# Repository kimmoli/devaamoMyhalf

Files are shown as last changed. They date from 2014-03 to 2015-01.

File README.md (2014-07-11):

devaamoMyhalf
=============

Myhalf edition for Devaamo

V1.10 Original design based on kimmoli Myhalf

V1.20 SMD connector added, pogopads relocated and resized to 2 mm dia, flash hole relocated

*V1.20 Shared at OSHPark https://oshpark.com/shared_projects/6TWMNB35*

Added stl files for clips, 0.8mm and 1.6mm PCB thicknesses.

See also http://talk.maemo.org/showthread.php?t=92329

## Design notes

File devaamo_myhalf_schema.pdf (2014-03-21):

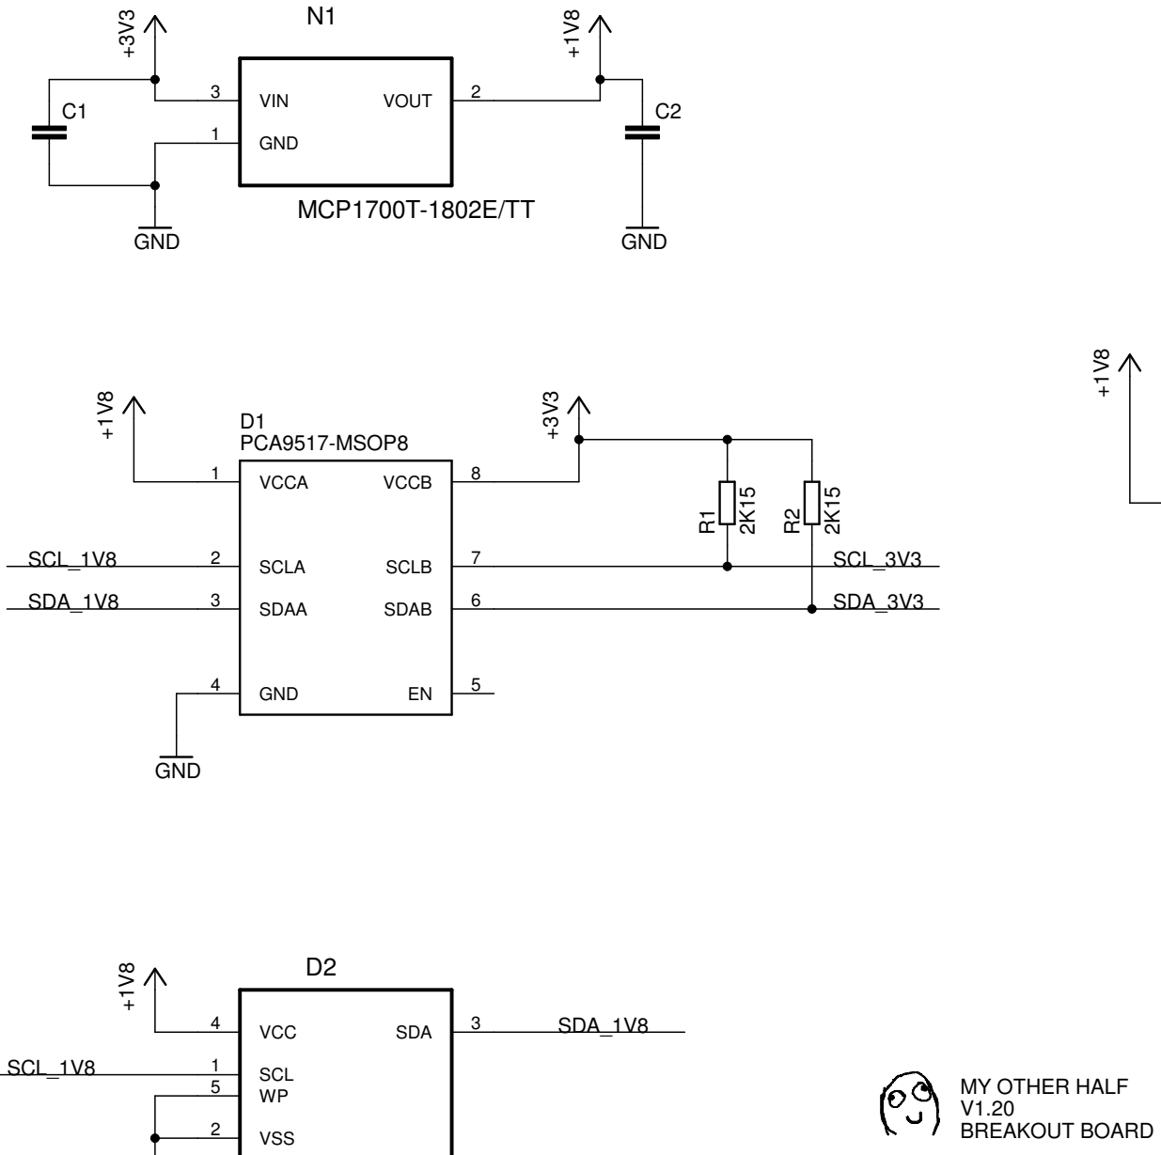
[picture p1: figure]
PCA9517-MSOP8; MCP1700T-1802E/TT; GND; MY OTHER HALF V1.20 BREAKOUT BOARD; VCC 4; SCL 1 WP 5; VSS 2; SDA; VCCA 1; SCLA 2; SDAA 3; GND 4; SDAB; SCLB; VCCB; VIN 3; GND 1; VOUT; SDA_1V8; SCL_1V8; SCL_3V3; SDA_3V3

21.3.2014 11:49:48 f=1.25 c:\temp\TheOtherHalf\devaamoMyhalf\devaamo_myhalf.sch (Sheet: 1/1)

SMD_1.5MM

SMD_1.5MM

SMD_1.5MM

SMD_1.5MM

SMD_1.5MM

SMD_1.5MM

AT24C02C-SOT23-5

GND

GND

+3V3

330

+3V3

GND

PIIKKIRIMA-10TH

GND

+3V3

PIIKKIRIMA-10SMD-WIRE

GND

+1V8

+3V3

CONNECTION TO JOLLA

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
INT | INT

SDA_1V8

SDA_1V8 | SDA_1V8

SCL_1V8

SCL_1V8 | SCL_1V8

VCC

VCC | VCC

GND

+3V3

SCL_3V3 | SCL_3V3
SDA_3V3 | SDA_3V3

OSHW
LOGO

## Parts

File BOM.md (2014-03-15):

DevaamoMyHalf V1.20 BOM
=======================

Bill of materials

Locator | Part
--------|--------------------------------------------------------------------------------
R1, R2  | 0603 2k15 (or 2k2) I2C 3.3V pullups. I usually use 2k15 from E96 series.
R3      | 0603 330 ohms or something like that for led series resistor
C1, C2  | 0603 1µF 16V X7R
H1      | 0603 Led of your favorite colour (for blue or white, change R3)
N1      | MCP1700-1802E (Microchip) in SOT23 1.8V Regulator
        | http://ww1.microchip.com/downloads/en/DeviceDoc/20001826C.pdf
D1      | PCA9517DGKR (TI) in MSOP8 (or PCA9517DP (NXP) in TSSOP-8) I2C Level translator
        | http://www.nxp.com/documents/data_sheet/PCA9517.pdf
D3      | AT24C02D-STUM-T (Atmel) in SOT23-5 I2C EEPROM 2kbit
        | http://www.atmel.com/Images/Atmel-8871-SEEPROM-AT24C01D-02D-Datasheet.pdf
X1      | 2.54mm (0.1") pinheader 10 pins, or just solder wires (Remember to cut even on phone side)
        | SMD Headers Vertical or right-angle should also fit

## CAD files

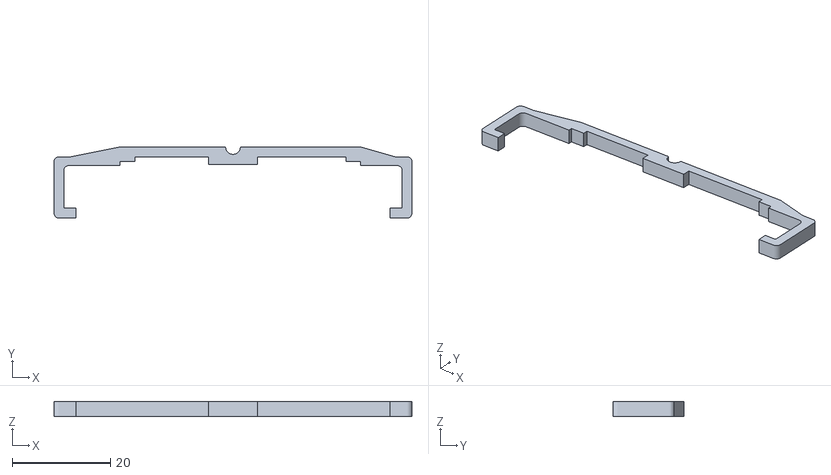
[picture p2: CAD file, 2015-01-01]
stl/Myhalf-clip-0_8mm-r2.stl
73.0 x 14.5 x 3.00

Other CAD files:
stl/Myhalf-clip-0_8mm.stl
stl/Myhalf-clip-1_6mm.stl

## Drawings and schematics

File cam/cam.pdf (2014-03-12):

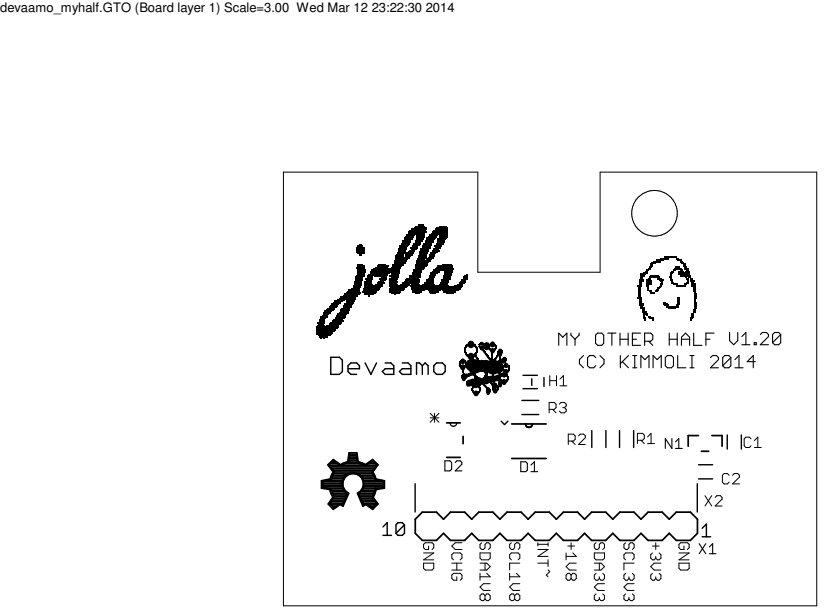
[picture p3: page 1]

devaamo_myhalf.GTO (Board layer 1) Scale=3.00 Wed Mar 12 23:22:30 2014

devaamo_myhalf.GTP (Board layer 2) Scale=3.00 Wed Mar 12 23:22:30 2014

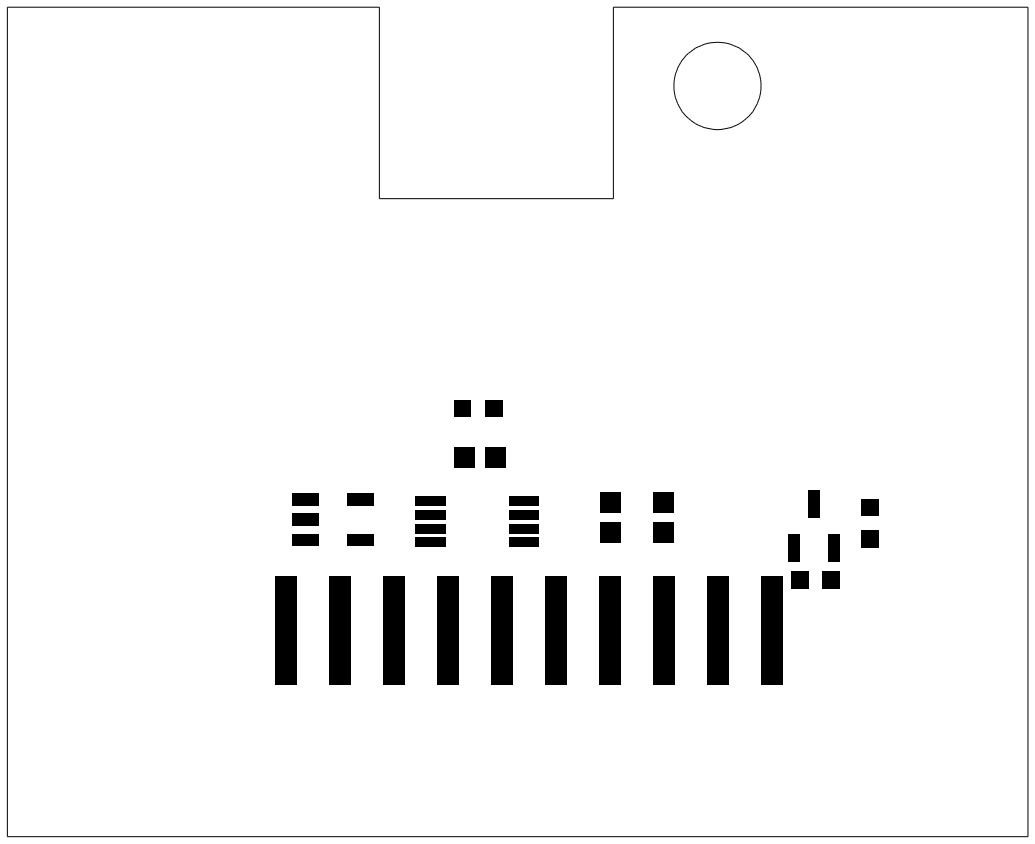
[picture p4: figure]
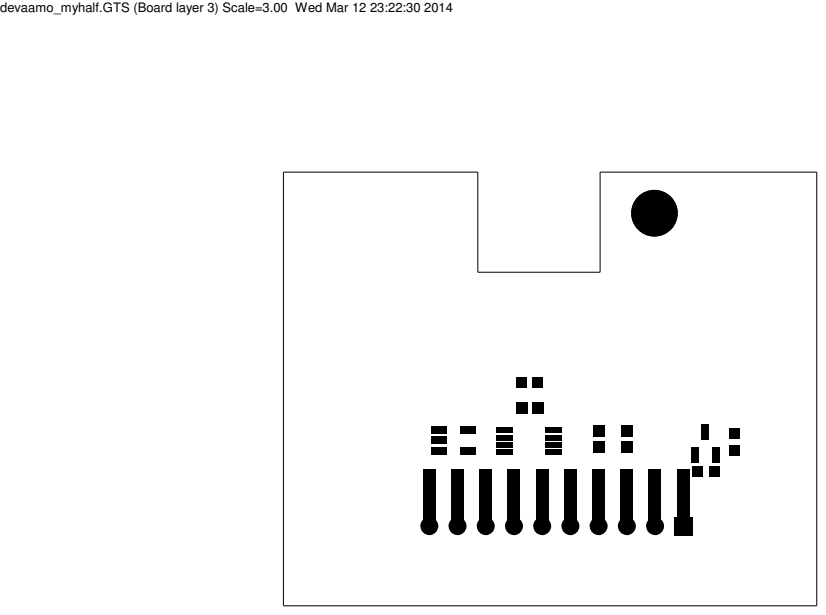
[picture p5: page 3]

devaamo_myhalf.GTS (Board layer 3) Scale=3.00 Wed Mar 12 23:22:30 2014

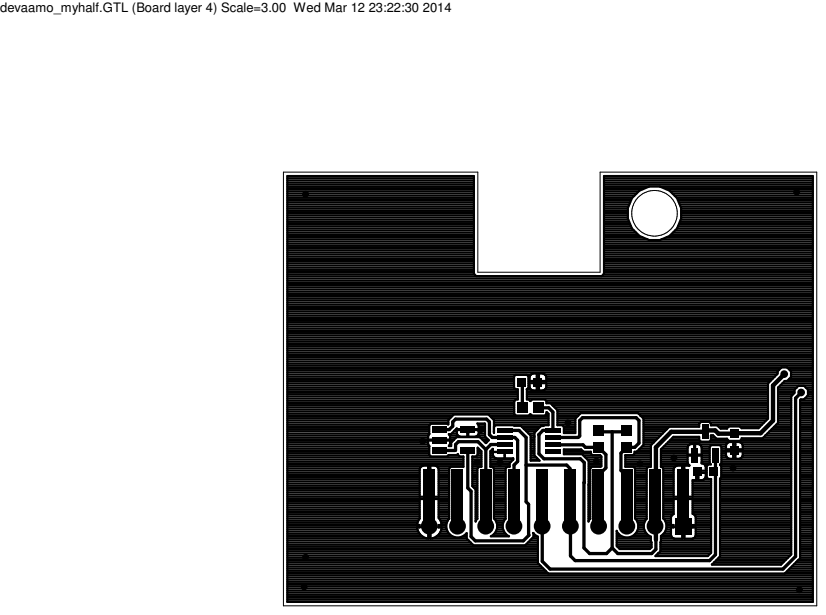
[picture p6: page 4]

devaamo_myhalf.GTL (Board layer 4) Scale=3.00 Wed Mar 12 23:22:30 2014

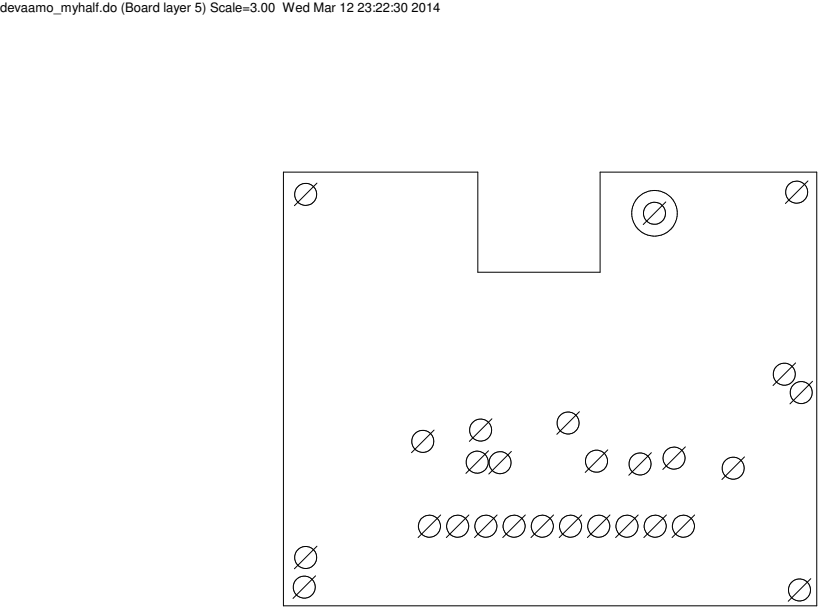
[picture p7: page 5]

devaamo_myhalf.do (Board layer 5) Scale=3.00 Wed Mar 12 23:22:30 2014

devaamo_myhalf.GML (Board layer 6) Scale=3.00 Wed Mar 12 23:22:30 2014

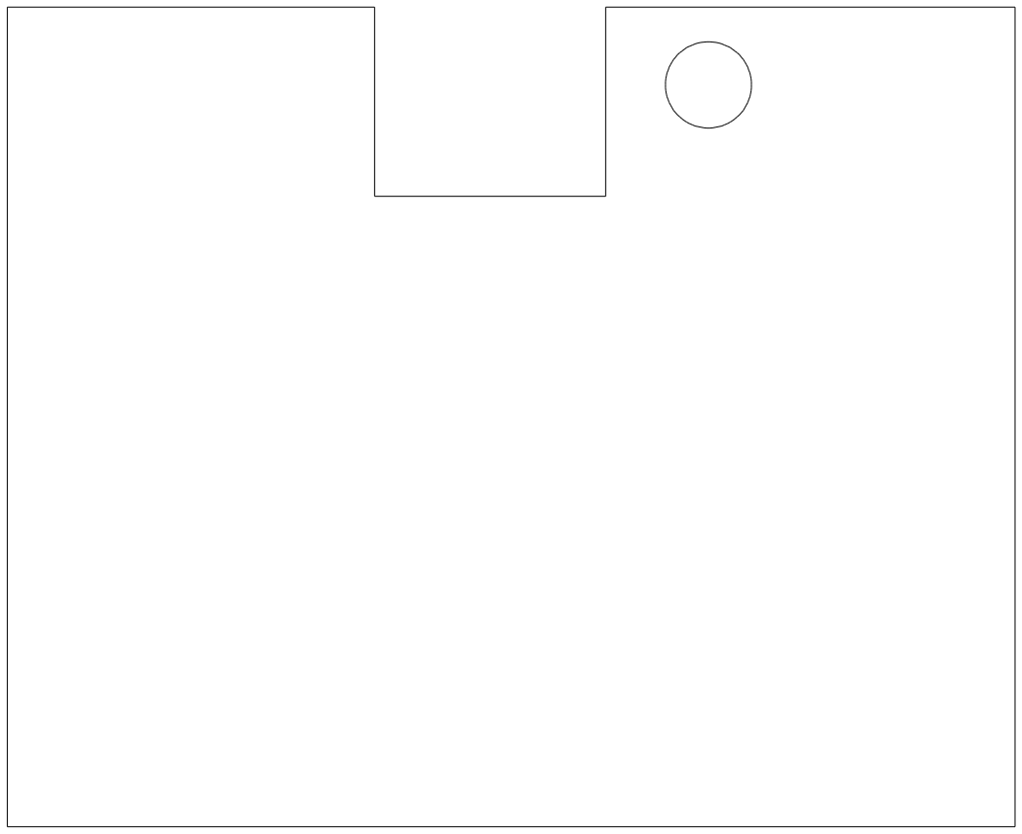
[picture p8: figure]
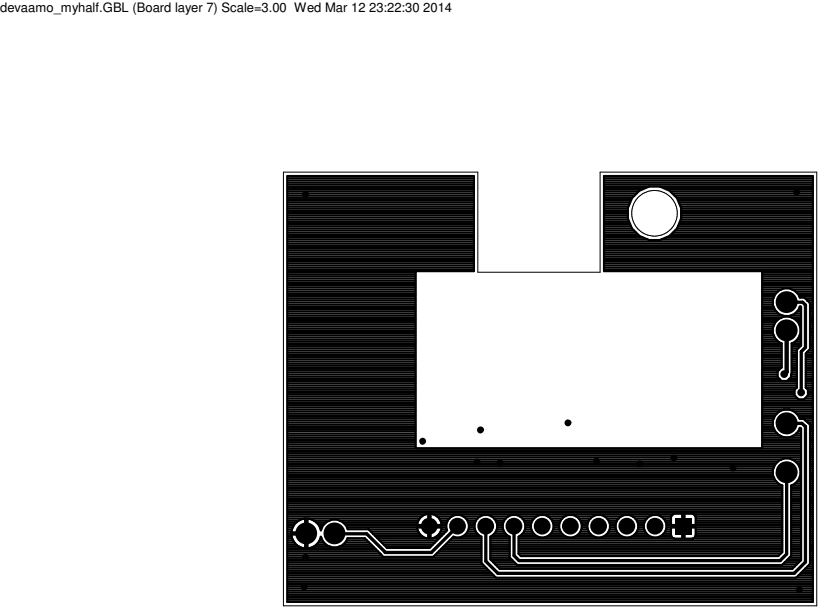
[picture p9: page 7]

devaamo_myhalf.GBL (Board layer 7) Scale=3.00 Wed Mar 12 23:22:30 2014

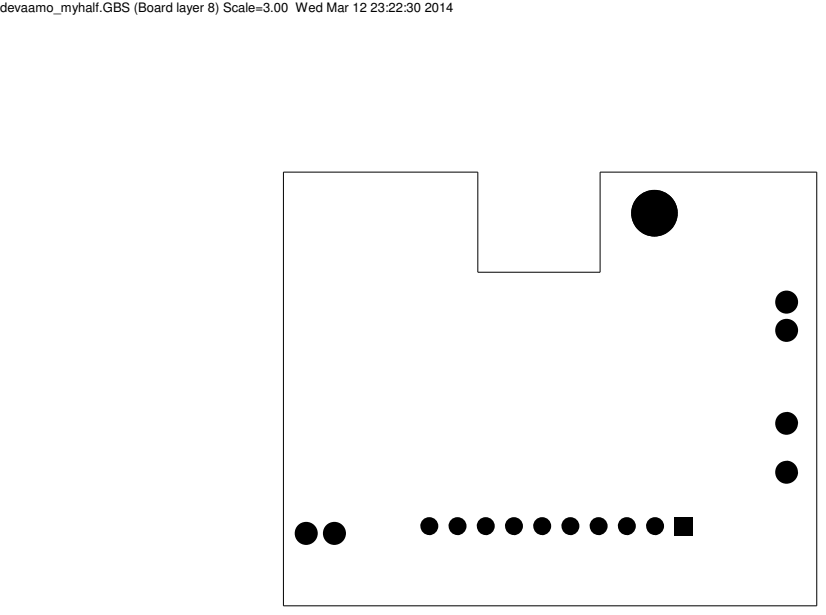
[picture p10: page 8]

devaamo_myhalf.GBS (Board layer 8) Scale=3.00 Wed Mar 12 23:22:30 2014

devaamo_myhalf.GBP (Board layer 9) Scale=3.00 Wed Mar 12 23:22:30 2014

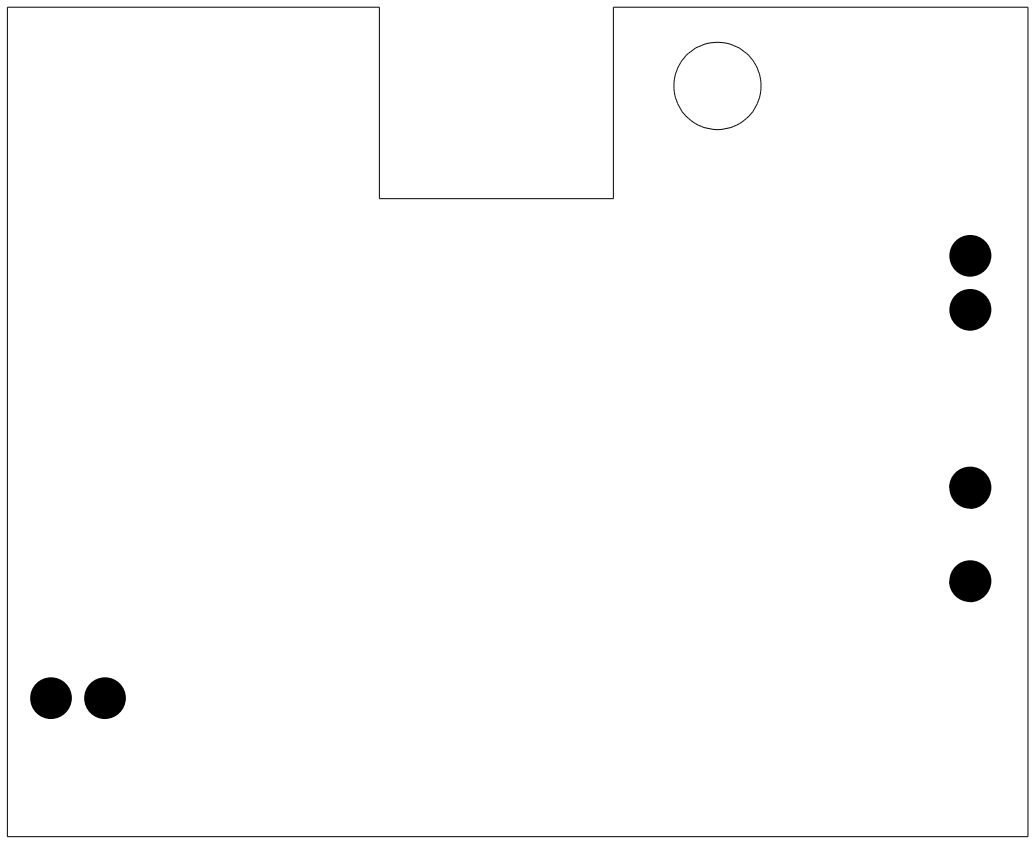
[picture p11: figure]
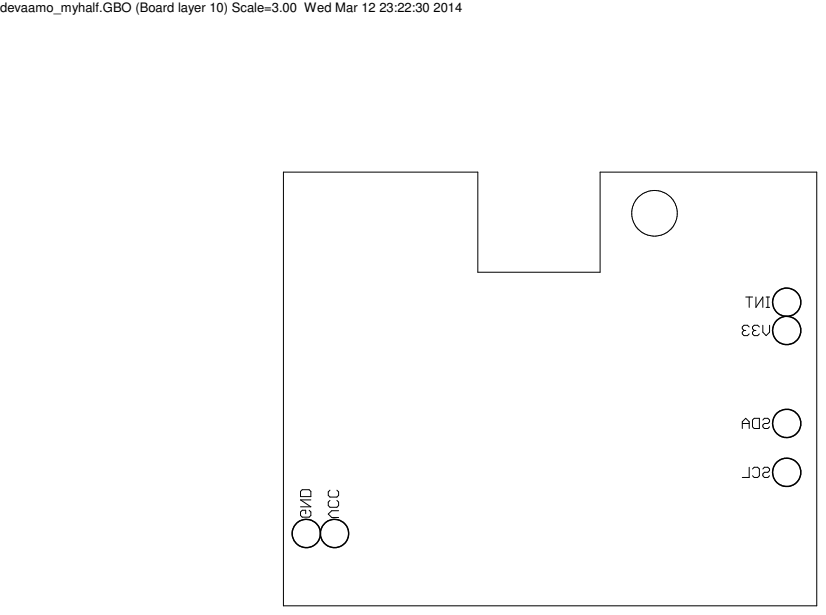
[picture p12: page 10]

devaamo_myhalf.GBO (Board layer 10) Scale=3.00 Wed Mar 12 23:22:30 2014

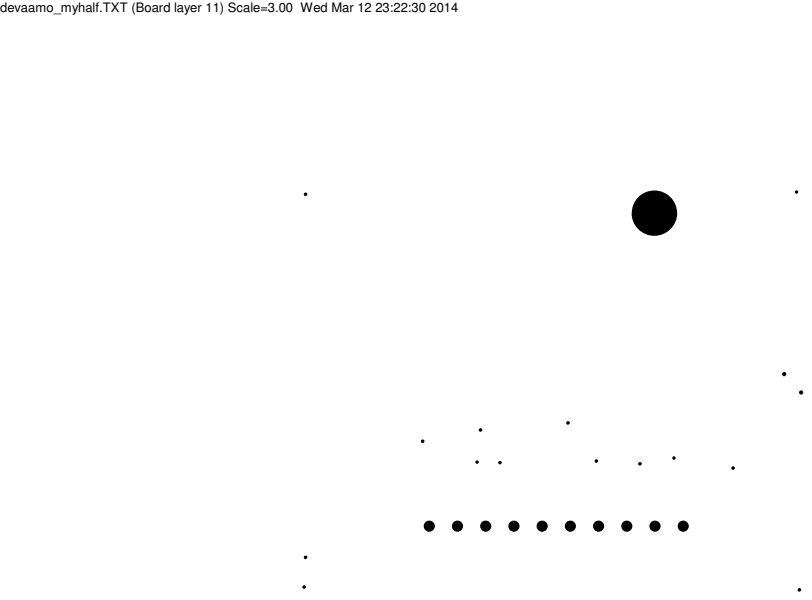
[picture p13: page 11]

devaamo_myhalf.TXT (Board layer 11) Scale=3.00 Wed Mar 12 23:22:30 2014

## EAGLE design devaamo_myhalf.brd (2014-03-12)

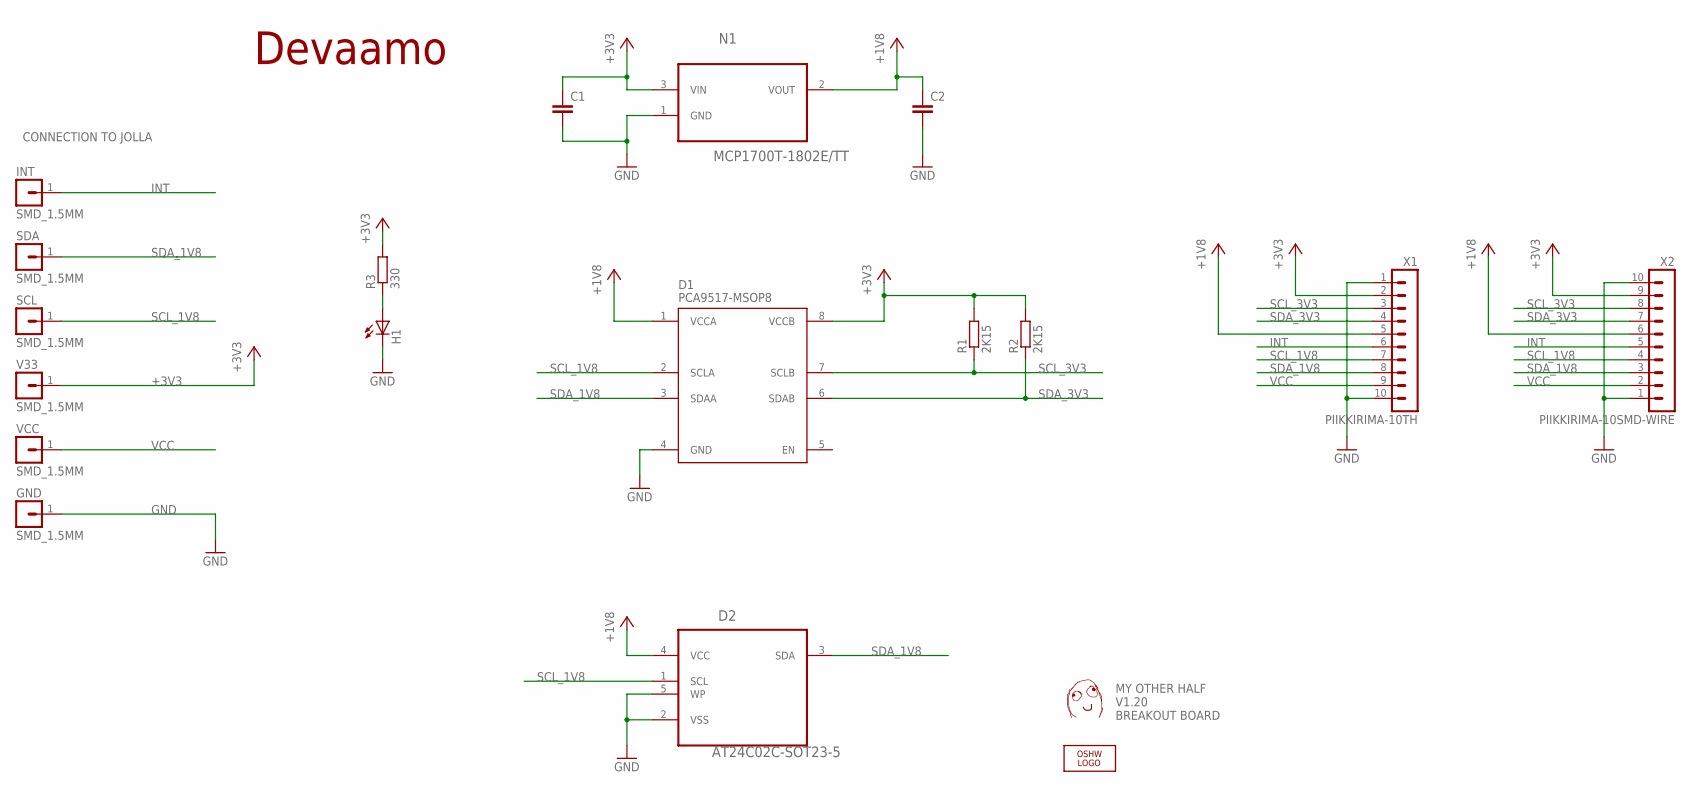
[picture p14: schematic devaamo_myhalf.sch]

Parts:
C1, C2: C-EUC0603; C0603
D1: PCA9517-MSOP8; SOP65P490X110-8N
D2: AT24C02C-SOT23-5; SOT95P280X145-5N
GND: SMD_1.5MM; SMD_ROUND_1.5MM
H1: LEDCHIP-LED0603; CHIP-LED0603
INT: SMD_1.5MM; SMD_ROUND_1.5MM
LOGO1: OSHW_LOGO_FILLX0200-NT; OSHW_FILLX200_NOTEXT
N1: MCP1700T-1802E/TT; SOT95P237X112-3N
R1, R2: 2K15; R0603
R3: 330; R0603
SCL: SMD_1.5MM; SMD_ROUND_1.5MM
SDA: SMD_1.5MM; SMD_ROUND_1.5MM
U$1: DAFUG
U$3: DEVAAMO
V33: SMD_1.5MM; SMD_ROUND_1.5MM
VCC: SMD_1.5MM; SMD_ROUND_1.5MM
X1: PIIKKIRIMA-10TH; PIIKKIRIMA-10
X2: PIIKKIRIMA-10SMD-WIRE; 61001018321

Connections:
+1V8: C2.1, D1.1 (VCCA), D2.4 (VCC), N1.2 (VOUT), X1.5, X2.6 (5)
+3V3: C1.1, D1.8 (VCCB), N1.3 (VIN), R1.2, R2.2, R3.2, V33.1, X1.2, X2.9 (2)
GND: C1.2, C2.2, D1.4 (GND), D2.2 (VSS), D2.5 (WP), GND.1, H1.C, N1.1 (GND), X1.1, X1.10, X2.1 (10), X2.10 (1)
INT: INT.1, X1.6, X2.5 (6)
unnamed: H1.A, R3.1
SCL_1V8: D1.2 (SCLA), D2.1 (SCL), SCL.1, X1.7, X2.4 (7)
SCL_3V3: D1.7 (SCLB), R1.1, X1.3, X2.8 (3)
SDA_1V8: D1.3 (SDAA), D2.3 (SDA), SDA.1, X1.8, X2.3 (8)
SDA_3V3: D1.6 (SDAB), R2.1, X1.4, X2.7 (4)
VCC: VCC.1, X1.9, X2.2 (9)

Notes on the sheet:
MY OTHER HALF V1.20 BREAKOUT BOARD
CONNECTION TO JOLLA

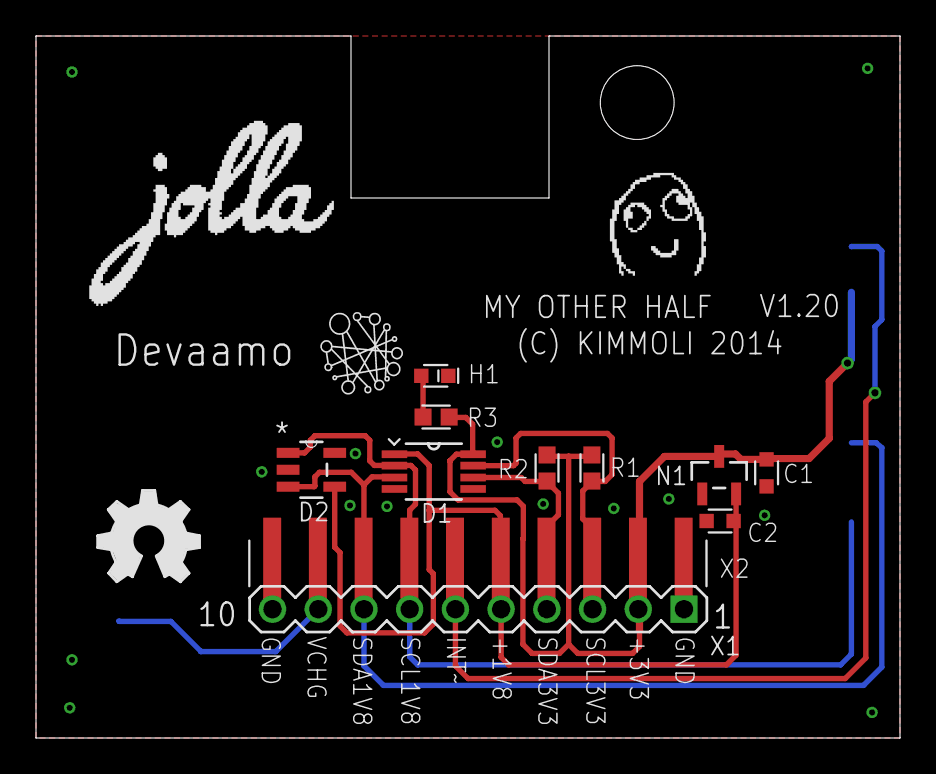
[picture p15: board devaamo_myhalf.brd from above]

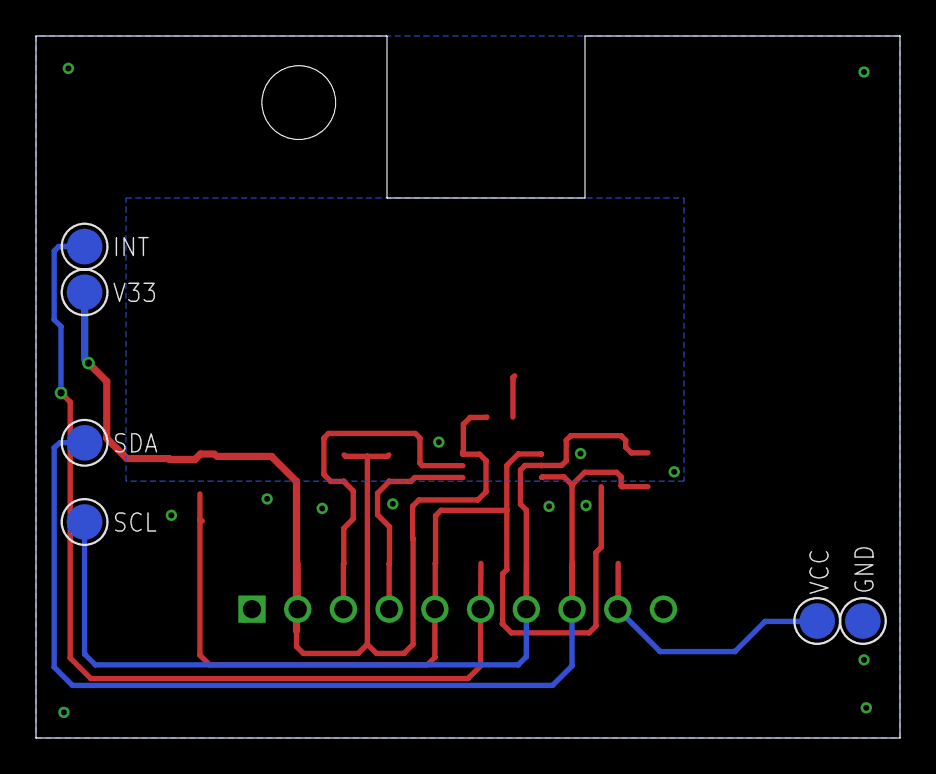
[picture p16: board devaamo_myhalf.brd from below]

Board: 2 copper layers, 48.0 x 39.0 mm, 21 parts (6 on the bottom side), 10 nets.

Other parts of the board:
U$2: JOLLALOGO

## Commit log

2014-03-12 V1.10 Original Devaamo Edition
    [devaamo_myhalf.brd, devaamo_myhalf.sch]
2014-03-12 smd connector add, relocate flash hole, resize pogopads to 2mm
    [devaamo_myhalf.GBL, devaamo_myhalf.GBO, devaamo_myhalf.GBP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]
2014-03-12 gerber pdf added
2014-03-12 oshw logo added
    [devaamo_myhalf.brd, devaamo_myhalf.sch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]
2014-03-15 Update BOM.md
    tableish
2014-03-21 add PDF schematic
2014-07-11 stl files added
    [Myhalf-clip-0_8mm.stl, Myhalf-clip-1_6mm.stl]
2015-01-01 rev2 0.8mm clip
    [Myhalf-clip-0_8mm-r2.stl]
